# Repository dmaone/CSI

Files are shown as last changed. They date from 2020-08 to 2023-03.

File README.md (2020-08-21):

# CommonSense Info

This repo holds CommonSense project paraphernalia: pinouts, assembly guides, gerbers, PCB photos - you name it.

[Common](Common.md) - common stuff, like layouts and threshold configuration

[Capacitive](Capacitive.md) - for Model F, beamspring, Topre, probably Plum

[Inductive](Inductive.md) - for ITW ferrite core switches (MagValve, Cortron, Licon..). Probably other inductive ones.

[uSwitch](uSwitch.md) - Honeywell MicroSwitch. SDxxxx

[Common](Common.md) - common stuff, like layouts and threshold configuration

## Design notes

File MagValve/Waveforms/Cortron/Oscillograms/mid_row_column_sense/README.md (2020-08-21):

In this experiment, probes are connected across the column, and the key in row 6 is pressed.

Somewhat expected, this doesn't cause any change to the columns closer to ground.

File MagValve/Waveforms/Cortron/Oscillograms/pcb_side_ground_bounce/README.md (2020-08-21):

This is measuring ground bounce between controller gnd and rows(?) gnd, when different rows are driven.

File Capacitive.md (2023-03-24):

# Capacitive stuff, IBM or otherwise

## Only switch-specific things are here. Most of the doc is in [Common.md](Common.md)!

# Planning: pinouts

* It is STRONGLY RECOMMENDED to set matrix size to your physical matrix size.
* There are some ready-made configurations for the default pinout in `config.h`.
* YOU MUST USE CONTIGUOUS ROWS/COLUMNS, STARTING FROM ZERO.
* Pins on the board are marked `0.0`, on envelope - `P0_0`, and in PSoC Creator - `P0[0]`. All 3 refer to the same pin. `2.3`-`2.7` means "2.3 to 2.7, including".
* Effort is made to make pins contiguous, but that's not always possible, so pay attention.

### Default pinout: Project "Capsense"

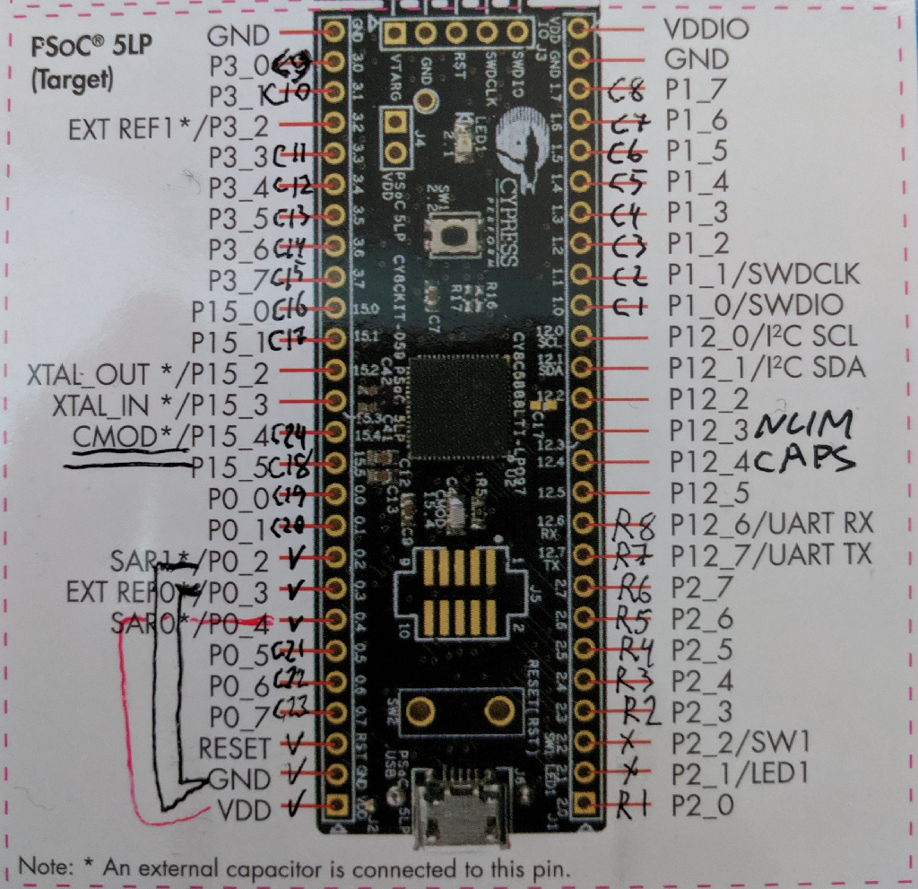
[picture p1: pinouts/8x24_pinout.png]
default pinout

**WARNING** to use column 24, **R5** (between `0.1` and `12.6`) MUST be removed.

If you don't - column will always read zeroes. Which is, for a NORMALLY_HIGH switch like Beamspring, means they will appear **PRESSED ALL THE TIME**.

* D0: `0.2`. Must be connected to the nearest `GND`.
* Guard: `0.3`. Must be connected to the nearest `GND`. Separate wire is **HIGHLY RECOMMENDED**
* ADC Vref: `0.4`. Must be connected to the nearest `VDD`.
* Rows: `2.0`, `2.3`-`2.7`, `12.7`, `12.6`
* Cols: `1.0`-`1.7`, `3.0`, `3.1`, `3.3`-`3.7`, `15.0`, `15.1`, `15.5`, `0.0`, `0.1`, `0.5`-`0.7`, `15.4`.

### If you're changing the pinout
* You'll need 35 pins. That's not much more than the kit has - so choose the layout wisely.
* rows are top(`Rows0[0]`) to bottom(`Rows0[7]`), columns are left(`Cols[0]`) to right(`Cols[23]`).
* Keep in mind that in FlightController everything is 1-based so normies can use it, so rows will be 1 to 8.
* P12(all pins of it) cannot be used for analog connections. That means you can only assign Rows to those pins.
* It is better to separate Rows and Cols by a pin electrically connected to the ground, but not necessary. If you use adjacent pins - one matrix cell will have higher readings, that's all.

## Additional Hardware configuration hints
* If key monitor only shows zeroes, no matter which keys you press - set ADC resolution higher.
* If even at 12 bits it still doesn't work - increase charge delay. Recommended setting is 18.
* If several keys fire at once - set longer discharge delay. I found that 180 (10 microseconds) works pretty well, but you can go even higher for increased EMI rejection.

## Configuring thresholds
**NOTE** for beamspring, invert direction, so max->min and adjustments are negative.

**!!!NOTE!!!** If you see double presses on some keys, set threshold higher - just under the steady pressed state. Some keys have physical bounce and there are two peaks. Controller is too fast and sees this as 2 keypresses.

Short version ():
* Click "Key Monitor" button.
* Click "Start!". Get the idea of levels that should be there - press keys, observe readings going up and down. Small numbers below 7-segment indicators are min/avg/max.
* Click "Stop!". Select "Max" into dropdown near the "reset" button, click "Reset", "Start!".
* Wait 15 seconds or longer, while readings stabilize.
* click "Stop!". Click "Set thresholds". Close window.
* Click "Thresholds" in the main window. put a small positive value (see below) into adjuster spinbox, click "Adjust".
* Click "Apply".
* Close threshold editor. Select "Config -> Upload" in menu. Test. Once you're satisfied with results, "Command -> Commit".

Thresholds should be set ~2x higher than most of the matrix settles on. For beamspring - probably 75% of the highest reading.
**TEST SETTINGS BEFORE COMMITTING**. If you get thresholds wrong - there will be a red "UNSAFE" light in the status bar and keyboard will refuse to produce output. It's supposed to retest settings after you upload. If it doesn't - click "Scan", it will try to restart scanning.

### Debugging the matrix
If something is wrong - you can still use matrix monitor using the following trick:
* open matrix monitor,
* make sure the mode is "Now"
* click "Start!"
* go to main window
* click "Scan"

The numbers under the "LCD" numbers are min/avg/max since last reset. Looking at those will tell you A LOT about what controller sees - but not everything, because in normal mode controller processes about 30 thousand rows per second and there is no way to transmit that amount of data over USB 2.0.

**WARNING** exit this mode in the reverse order (or by pulling out the USB plug), otherwise you'll likely have to reboot.

This is mostly useful for beamsprings - because all keys are down in beamspring by default. Model F is much easier - everything is up and you can just press a key to observe the effect. So, recommended debugging strategy - pull out the PCB, lay it down over grounded conductive surface, start matrix monitor, put one flipper (or a small coin) over the PCB and observe the changes. If several rows/columns change at the same time - you have a short between those, find it. If readings are normal but assembled keyboard is unstable - it's likely a ground problem.

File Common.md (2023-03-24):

# Things that are applicable to firmware in general, not switch-specific

### ExpHdr (AKA "Solenoid connector")
Configured to blink the kit's LED on keypress. `12.4` is a CapsLock LED, `12.3` - NumLock.

**Leave it alone, unless you really know what you're doing. You can permanently damage GPIOs if you fuck up here.**

DO NOT POWER ANYTHING FROM GPIOs. Max GPIO source current is 4mA. FOUR. MILLIAMPERES.

So, `ExpHdr0`(`12.3` by default) would be "enable" line, and `ExpHdr2` (`2.1`) is the "fire" line. Delay settings are in "Hardware" section of FlightController. `ExpTgl` "USB scancode" toggles between normal operations and "all GPIOs are pulled to the ground".

# Soldering

I recommend flashing initial firmware plus some safe configuration first. It's just easier to plug the empty kit in - for initial flashing you'll have to plug the whole kit into standard USB socket, and that might be hard with a big hunk of metal attached to it.

### SOLDER THE KIT SO YOU CAN SEE THE CHIP.

It's in CAPS because I was stupid enough to solder it chip (and LED) facing backplate and blinking LED debugging without seeing the led is pain.

### Grounding considerations
Ground. Does. Not. Matter.

As long as you connected ALL the metal parts adjacent to PCB **and** PCB ground with ANY of the GND pins of the kit - you are fine. Stop worrying about it.

If your PCB doesn't have any vias - MAKE SURE YOU CONNECTED ALL GROUND TRACES ON BOTH SIDES OF THE PCB to controller ground. Floating traces are bad, mmkay.

Except if you see very unstable readings (matrix monitor over 15 seconds with no keypresses shows something like 1/50/255). Then you _probably_ have a ground quality issue.

When in doubt - use star ground. That is, connect all the things that must be grounded (basically, ALL THE THINGS except rows and columns) to a single point, using different wires.

## Hardware configuration hints
* If you're using Linux and can't connect - run as root OR fix your device permissions. No, I don't find fucking with your udev enjoyable, thank you very much.
* If you see the red UNSAFE in the bottom right corner and what to know why - see "Debugging the matrix" in switch-specific README
* If you see double actuations on keypress - increase debouncing steps.
* If you haven't touched ExpHdr pins - "Solenoid" mode and drive time set to 100 will make a LED on the kit blink with every keypress (not in setup mode). Smaller setting will decrease brightness.

# Flashing "default" firmware
This section is removed to stop causing stupid questions.
You MUST build. Deal with it.

# Building custom firmware
You'll need Windows machine. Mac with VirtualBox will do - but a couple of notes there.
You'll need to download [Virtualbox](https://www.virtualbox.org/wiki/Downloads) (v5.2.2 was used) - don't forget the extension pack - and a [windows image](https://developer.microsoft.com/en-us/microsoft-edge/tools/vms/) - I used "MSEdge on Win10". Download, unpack, click the .ovf, wait for import to complete. Then open settings (right-click, "Settings"), click "Ports", select "USB" tab, enable USB 2.0 controller, click the plug with blue dot. THIS WILL CONNECT ALL NEW USB DEVICES TO YOUR VM. Run the VM now. You have your windows development environment now. Download PSoC creator into VM, install (typical works just fine), and continue.
Linux with Virtualbox will probably work too - but not tested as I don't have any hardware running Linux and running virtualbox inside virtualbox is not something I plan to do anytime soon.

Download and install [PSoC Creator](http://www.cypress.com/products/psoc-creator-integrated-design-environment-ide) - you actually can download without suffering akamai download manager. Typical install works just fine. v4.3 was used, though newer should work too.

### Bootloader
You likely don't need to change bootloader - but building it will verify that your development environment is set up correctly.
* Open PSoC Creator
* File -> Open -> Project/Workspace, find "CommonSense.cywrk" and open it.
* Select "Project 'Bootloader'" in "Workspace Explorer" on the left, right-click, "Set as Active Project".
* **IMPORTANT:** Select "Release" in the combo box on the top toolbar that likely displays "Debug".
* Right-click again, "Device Selector", find and select "CY8C5888LTI-LP097". It's likely selected already.
* Press Shift-F6 to build bootloader.

#### Important troubleshooting notes
* "DTD prohibited for security reasons" means "you used ClownZip, and it couldn't decompress the .zip"
* "Unable to find component X" - right-click on top-left item in the left tree editor ("Workpace 'CommonSense' (7 Projects)"), click "Update Components". It should download the missing parts.
* Compilation errors: pay attention to the **IMPORTANT** warning. If it says "Release" - ask at DT, but see the top paragraph. You get support that you paid for (and you can't pay and there are no plans for that).

### Firmware
I will use "Capsense" as a project name, but if you don't want to have merge conflicts in config.h every time you pull - you can copy+rename the project. You will only copy programmable hardware settings (which will not change - I run that since 2017 and never had to) and config.h. Everything else will NOT be copied, so you will get all the updates.

Do a smoke test first: Repeat the "Bootloader" part for the Capsense project.

When that succeeds - it's a good time to make your firmware customizations.

`Capsense.cydsn/config.h` is a config file. You can set number of rows, columns and layers there, as well as switch type. There are presets for popular configurations, activated via `#define HARDWARE_VARIANT HW_X` - or you can use `#define HARDWARE_VARIANT HW_CUSTOM` if you know what you're doing.
Again: **build without any changes first**!

For non-default pin mapping: Expand a project in the left pane, click "Pins" in "Design Wide Resources". You will see chip model and a table in the big window. Assign pins according to plan.

The Big Moment: plug the kit in. The "gold fingers" part goes into the USB socket.

Press "Ctrl-F5" (Debug -> Program). PSoC Programmer will likely demand to update KitProg - it will walk you thru. Refer to "Flashing "default" firmware" section for troubleshooting tips.

---
It's time now to disconnect the board, peel that polyimide film off the micro USB socket, find the micro-USB cable in the cable mess under your table, and plug it into "Target" part of the kit.

..I was able to plug _both_ ends into the same USB hub (thinkpad docking station) without frying anything - but your mileage may definitely vary.

You may optionally break the kitprog away in a symbolic gesture, but a) if I were you, I wouldn't - not until you set everything up successfully at least - and b) cut the laminate at the snap-off line first. Doesn't have to be all the way (though you certainly can if you're looking for excuse to dremel things), but enough so the board doesn't buckle so horribly and I2C/RS323 traces are not lifted from the substrate. Oh, and soldering probably have to wait until this moment at least.

# FlightController

FlightController is an utility which allows runtime configuration of keyboard parameters

The building process is quite involved (See Qt-build/README.md in CommonSense) - at least on Windows. OS X requires homebrew AND XCode, but is scriptable.

There are Windows and OS X version in the [Releases](releases) section of CommonSense repo.

## Configuring layouts
Pretty straightforward. If thresholds are configured, pressed keys will be highlighted by "yellow highlighter" color and focused on. If you have another keyboard - pressing a letter there will change combo box value to that letter, allowing for VERY quick layout generation.

"Layer mods" configures what Fn/LLck buttons do. Press F to ~~pay respects~~ scroll to those - several times. It will cycle thro all USB scancodes starting with "F".

"Import" and "Export" will load and save to file. Format is compatible with xwhatsit layout files.

IF you see keypresses in setup mode, but not in normal - check out global.h, #define NOT_A_KEYBOARD. If it's 1 - change back to zero.

## Macros and delays
Figure it out yourself, please. It's not that hard. Delays are the _library_ of delays which will be used in macros.

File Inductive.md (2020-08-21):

SO YOU HAVE COME. (https://www.youtube.com/watch?v=k0VvMUD5vBY)

Remember that guy? Yeah. This is _that_ level of difficulty.

There's no matrix monitor - the programmable hardware is totally different and is, essentially, a 4-channel xwhatsit reimplementation, the only deviation being a separate DAC (hence threshold) per channel, each channel sitting behind a 4-channel multiplexor.

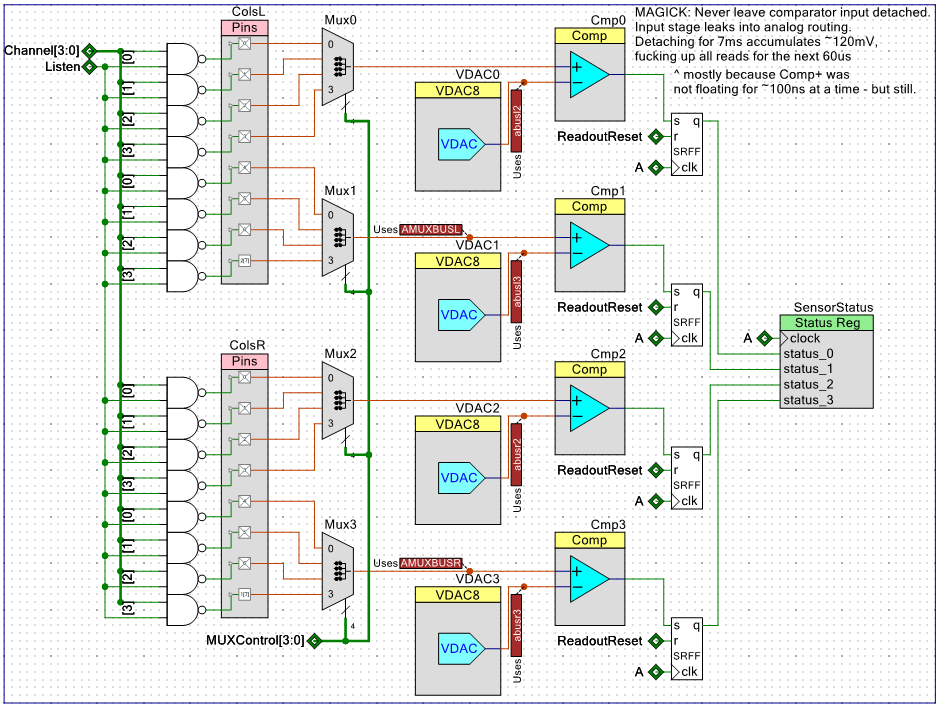
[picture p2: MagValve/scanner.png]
scanner


So it's back to blind tuning, and there's no autotune support xwhatsit util had. Partly because I'm a bit short on time recently, but largely because out of 3 test devices all 3 worked with same thesholds. I was able to literally solder a different keyboard to the same controller and it just worked with the thresholds from another - and to program a new controller, solder it to the third keyboard and just needing to correct for just a couple of keys, problem being "spacebar triggers if you press basically anything else".

Not much is known about what's _really_ going on inside the matrix, but I intend to get a bigger scope and figure this out in a couple of weeks while I still have access to the hardware.

# Before you begin
* If you're wondering what you've got - [there is a guide](http://telcontar.net/KBK/ITW/)
* This is optional, but highly valuable for troubleshooting: take high-res digital photos of both sides of your keyboard. High-res enough for traces to be 5px wide. Invaluable for tracing things.
  * Bonus points if you can fit all the board on one photo - stitching multiple photos is an ungrateful job.
  * Reference photos (too large to be inlined):
	  * Black is ground, colors are rows/columns. They are messy, because it's not easy to find 20 different colors and I had to resort to patterns.
	  * [Cortron 35-500079](MagValve/Cortron_35-500079_map.jpg) from [this mysterious beast](https://deskthority.net/viewtopic.php?f=62&t=19441)
	  *  [Cortron 55-500056](MagValve/Cortron_80-551101_rev_D.JPG) from [Raytheon model 930898-94](https://deskthority.net/viewtopic.php?f=2&t=23644)
	  * [Harris F190 22D](MagValve/Cortron_125-500451_map.jpg)
	  * [Nifco EKBB005A](MagValve/Nifco_EKBB005A.jpg) from [Telecomet type Σ3100](https://deskthority.net/viewtopic.php?f=2&t=23262).
* Find row/column driver chips. They are relatively inconspicious: rows terminate at 74145(can be 2 of those) and columns - at 7442. Those are both BCD decoders, 7442 is stronger drive.
  * If your board has Mitsubishi chips - the conversion formula is M(53200+{74-series model})P:
    * 7416(74**0**16) is M53216P.
    * 7442 (74**0**42) is M53242P
    * 74145 is M53345P
  * Sometimes, both decoders are 74145.

# Prepping the board
## LED concerns
Some boards have LEDs with drivers that are active high. So far, 2 ways to drive those was discovered:
* [SN]7416, LEDs hanging from power rail
* 75452 with ganged outputs, driving LED directly.

If you want to use those - don't **ACCIDENTALLY** power the whole board.
Recommended way is to cut drivers' Vcc trace from the rest of the board and power them from controllers' VDD or VDDIO pins. This can be awfully inconvenient in case of LEDs hanging from power rail, in which case you might elect to power the whole board, but watch for USB power consumption - don't fry the USB port.
**WARNING: Don't power LEDs** (or anything else!) from GPIO pins. Not only it won't work, **you'll fry the GPIO**.

## Remove the drivers
Hot air is your weapon of choice, but solder wick or even dremel (From the top side!) work just as well - you won't need those anymore. Just try not to damage the pads.
## Find columns common point and ground it
If you see 10-ish diodes on the PCB, connected together on one side - congratulations, you found it. Diodes may be scattered around the PCB (as is in Harris case) - but then they all connect to a common bus.
**Cross-check:** those diodes are connected to 7442 via keyboard matrix.
Connect the diode cathodes (the band side), to the ground rail. Double check it's ground rail - just shorting diodes is not enough as their common point is NOT ground.

NOTE: You might find MC833P chip instead of diodes. It is, essentially, 8 diodes.

If you plan to use LEDs (see below), you may want to desolder diodes and connect the column traces to the ground directly.
## Find rows common point and ground it
Look for a swarm of jumper wires (or vias) between row traces, near 74145(s). Connect any of those vias to ground (
* Connect common point of rows (it's close to 74145(s), look for a swarm of jumper wires (or vias!) between tracks that go alongside the row traces) to the ground rail.
**PRO TIP:** pin 7 of 74145 is ground.

## Solder the interface wires
Find the place for the controller, trace, measure, cut, tin, solder.
Wire quality seems not to matter - I used ribbon cable with some janky totally-not-copper conductors, and it worked OK 4 times out of 4.

I used different ground conductors for rows and columns - there's significant current flowing in rows, after all - but this is totally optional.

**!!WARNING!!** Cortron makes PCBs from unbelievably shitty phenolic paper and pads delaminate if you just look at them wrong, let alone touching. Be extra careful. They also give off awful ammonia smell when heated.

# Preflight checks
Resistance between the ground and any column or row wire end must be 1.5 to 2.5Ω. It seems to be around 0.2Ω/switch, but my ohmmeter has 0.1Ω scale, so it's not very trustworthy.

If all rows have same resistance to the ground and it's around 360/580Ω - you have not grounded the rows common point (see above).

# Assembly
Most recommendations from capsense part still apply, except for pinout.

## DO NOT touch columns. Not even reorder.

Columns laid out that way because it's the only way to fit 4 analog MUXes onto the chip.

Don't worry about column order. Solder in a way that will make cabling easier. You'll fix it all in layout. Cortron with a numpad has batshit insane layout anyway, you won't make it worse.

## Severe Weirdness Ahead
"Rows" work MUCH better when routed to where 7442 was.
I know, I know, 7442 drives physical columns. But since physical layout is insane anyway, there's no harm transposing it. It literally *cannot* be made worse. In return you can make matrix "shorter" for faster scanrate - and considering level of debouncing MagValves require it's a pretty useful change.

## Default pinout

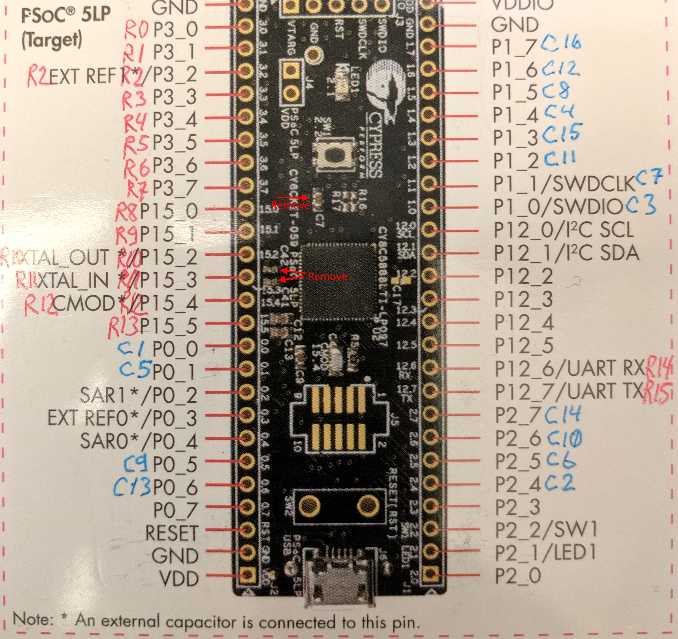
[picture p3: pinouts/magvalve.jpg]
Default pinout


Note that you will need to desolder 3 capacitors if you don't remap the rows. It's not that hard - just use the wide tip and some flux. Rest the tip on the capacitor and just nudge it off the pad after a couple of seconds. Sometimes just lifting the tip will pull the capacitor away.

# First Startup

First run will almost certainly result in [UNSAFE] condition.
* Go to hardware settings, verify charge delay is 20+ and discharge delay is 3-4.
* Debouncing must be set to **at least** 4 - 16 is recommended for the fist run.
* Set all thresholds to 15, apply values.
* Upload, COMMIT (Warning: takes several seconds), REVERT(essentially just a hard reset to ensure settings are applied), reconnect.

This usually results in a working keyboard. If some keys don't register - drop thresholds to 10, don't forget to upload changes. The best way to verify operation is to open Thresholds window while keyboard is in setup mode. Pressed key position will be highlighted yellow.

* There can be a key that trips when others are pressed. Bump that key's (or all keys) threshold couple notches
* Some keys might flicker. That's usually a sign of a threshold too high.

Once you achieved stable operation - find lowest debouncing interval that's still stable. I found 4 to be OK, less than 4 starts to give off spurious keypresses.

# OK, so it doesn't work.

## I pressed 20 keys at once and there's key spam
[STOP IT!](https://www.youtube.com/watch?v=4BjKS1-vjPs). I'll eventually have a separate doc with oscillograms which explains why that happens. But seriously. Stop it.

## Single row/column doesn't register
* For rows: make sure you removed capacitors indicated on pinout picture.
* Desolder affected line from controller. Verify resistance between line end and controller's ground pin.

## Scanner trips the sanity check no matter the settings

### Diagnostics
Follow this checklist, uploading config after each change. Stop when it's green AND some keys register.
* Set debouncing to 16.
* Set discharge delay to 50 or even 100.
* Set thresholds to 250. It should be green but keys wouldn't work (CHECK if they are!).
* Lower threshold to 100 - 50 - 25 - 15

### Interpretation
* Debouncing or discharge delay fixed it
  * Wires too long and/or too thin?
  * EMI sources in close vicinity? (dimmable LED lamps, DC electric motors, aliens...)
  * If the board is powered - interference from the old controller?
* Thresholds either high (>30) or very unstable
  * Verify **physical** row and column common points are securely grounded.
    * For rows: Verify low (<0.1Ω) resistance between ground and every between-rows trace.
    * For columns: Try to desolder (or just cut out) the diodes, and connect the cathodes (the pads that go to columns, not the common rail) to the ground. Verify resistance between column line and the ground.

# Some insane shit is happening
* Some keys don't register, or only register when you touch the plate with your other hand.
* or register only if pressed FIRMLY, and even then may only intermittently register.
* or register only if pressed firmly AND then shifted left/right/up/down.
* or register only you put something **FOR THE LOVE OF GOD, NON-CONDUCTIVE** under one side of the PCB and press firmly.

Congratulations, you're in for the Total Resoldering.

## If you have a scope
This won't save you from the resoldering. But you can at least confirm that rework will help.
Connect your scope to the row which has a problematic key, and set discharge delay to 10-15 (don't forget to move it back to ~4 after the experiment! Prolonged shorting of the GPIO to the ground is a surefire way to fry it!) and observe.

Let's look first at the good signal first:

![good][MagValve/good.png]

And now at bad:
![bad][MagValve/bad.png]

It's mostly explained in the pictures - but one tell-tale sign is left out: the post-impulse oscillations. The good signal drops to the ground quickly and stays there. The bad is much wigglier. If you see that - rework is your ticket. If not - I don't know what it is, you're on your own. I can speculate looking at your scope screenshots, but by the time you're reading it I won't have ANY cortron boards in my reach. 

## Total Resoldering
Leads on at least some of those switches are made of some strange material which repels 37Pb63Sn solder.

How to tell: touch the solder joint with a soldering iron (give it some flux up front, because that thing was made 50 years ago, it has oxide CRUST on it, not "film") - and observe solder JUMPING away from the lead.

It takes copious amounts of RMA flux (I used DeoxIT RSF-R80-2) and a scraper tool to convince it to take some tin. The tool (and what happens after heating the joint) looks like this: https://www.instagram.com/p/B251_1UjHZ7/. It is made from a diode because that's what I had on hand. It doesn't have to be a diode - just some sturdy wire with a loop on it. Or a wire brush. Improvise.

Leads had to be bathed in flux and scraped for 10-15 seconds, repeatedly - with new dose of flux applied to the lead every round.

I am NOT joking about scraping.

Even with scraping, after washing away the flux residue I see lots of "cold joints" and even holes in the solder between lead and the pad - but it works, and it's not my keyboard so I'm not going to switch to OA flux (or even IA/tip tinner) and have a chance to corrode everything in a couple of years. RMA barely cuts it, even after 30 seconds of bathing in a continuous supply of it.

Unfortunately, I didn't measure resistance before the resoldering operation, so I don't know how large it was. If you encounter one of those boards - please don't forget to measure the resistances beforehand and drop me a note - by email or via PM on DT - or even in the topic.

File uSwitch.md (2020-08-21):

# Untested prototype firmware

Supposedly works with "microswitch" keyboards.

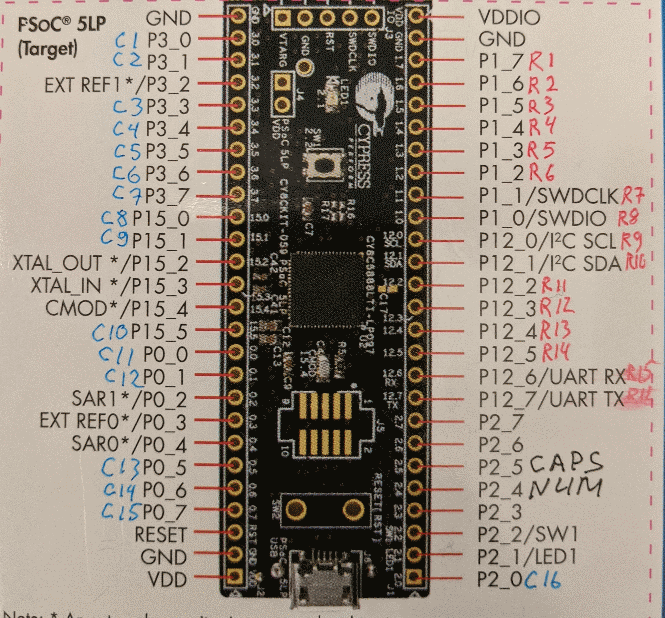
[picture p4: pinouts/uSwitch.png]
default pinout


Scans at 200kHz, so should have plenty of time detecting those 60us pulses from pulse switches.

Please reuse pullup resistors from original keyboard - but if you can't and scan doesn't work with bare switches - go to TopDesign.cysch and change pins to resistive pullup and initial drive state to "High (1)". That should do the trick.

If you can get it working - let me know :D

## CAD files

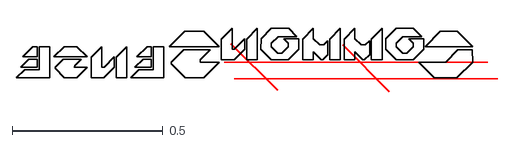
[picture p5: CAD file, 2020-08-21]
PCB/commonsense-logo.dxf
1.60 x 0.209

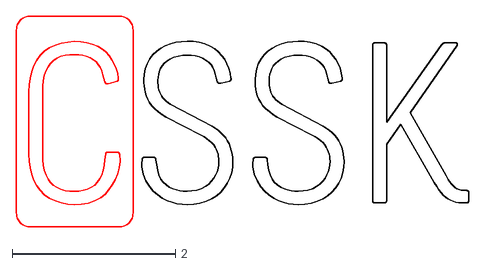
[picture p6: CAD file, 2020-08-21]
PCB/CSSK/CSSK2.dxf
5.54 x 2.58

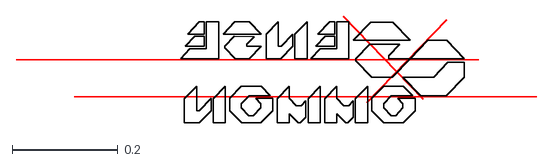
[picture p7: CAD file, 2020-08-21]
PCB/commonsense-logo-compact.dxf
0.983 x 0.202

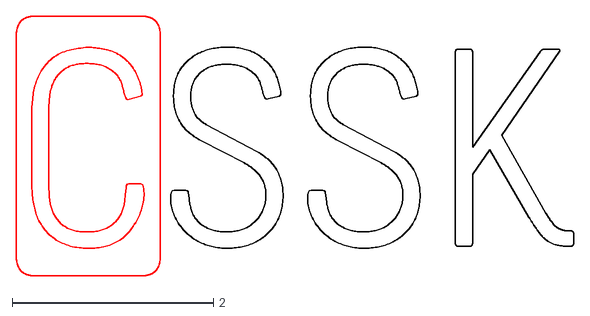
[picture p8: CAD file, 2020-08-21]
PCB/CSSK/CSSK3.dxf
5.54 x 2.58

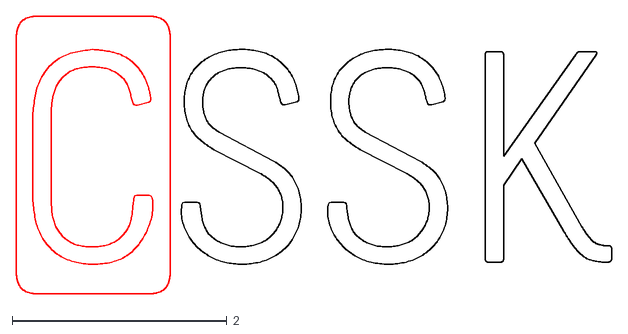
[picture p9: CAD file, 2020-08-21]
PCB/CSSK/CSSK9.dxf
5.54 x 2.58

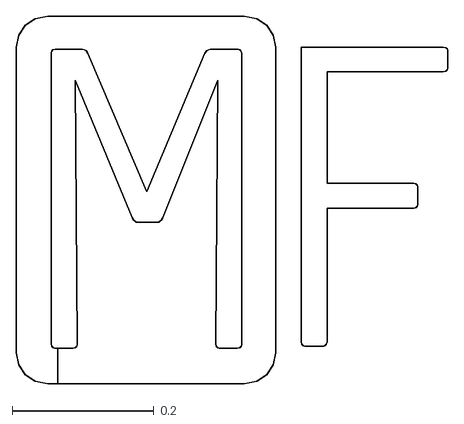
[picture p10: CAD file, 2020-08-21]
PCB/MF-logo.dxf
0.608 x 0.519

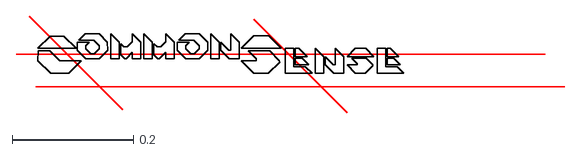
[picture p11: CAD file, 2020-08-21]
PCB/commonsense-logo-24mm.dxf
0.905 x 0.159

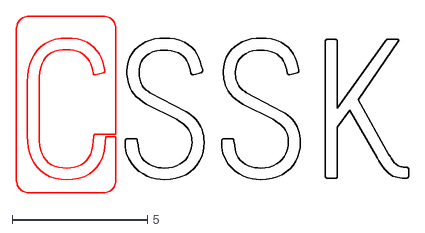
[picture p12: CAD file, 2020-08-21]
PCB/CSSK/CSSK.dxf
14.5 x 6.53

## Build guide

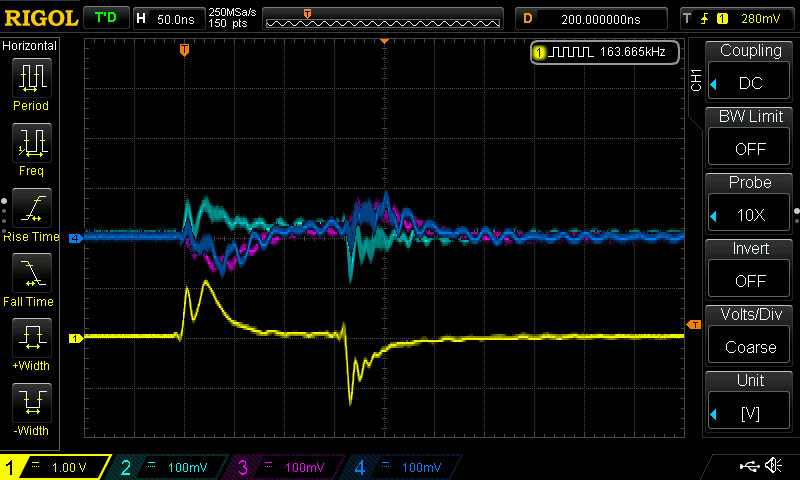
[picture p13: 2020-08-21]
MagValve/Waveforms/Cortron/2_rows_ground_at_far_end/DS1Z_QuickPrint12.png

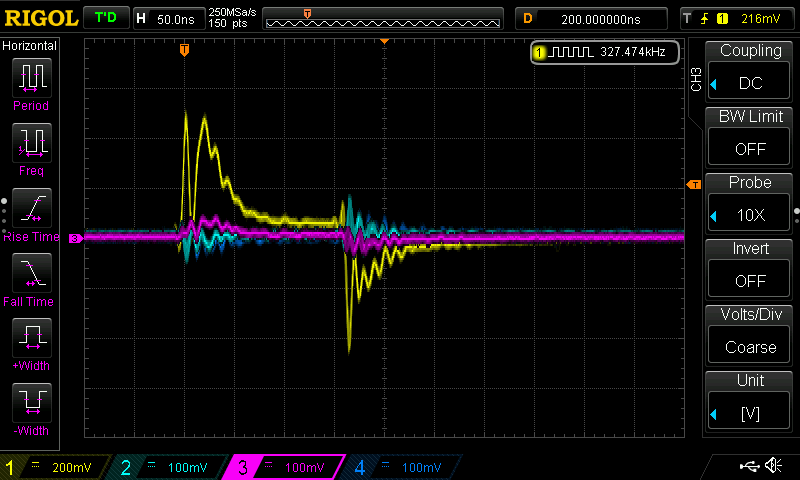
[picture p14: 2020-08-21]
MagValve/Waveforms/Cortron/2n_matrix/DS1Z_QuickPrint7.png

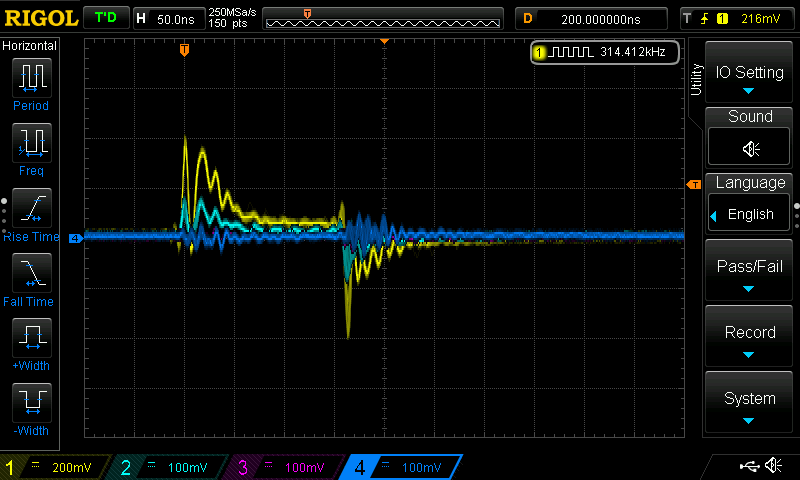
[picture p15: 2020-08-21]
MagValve/Waveforms/Cortron/2n_matrix/DS1Z_QuickPrint1.png

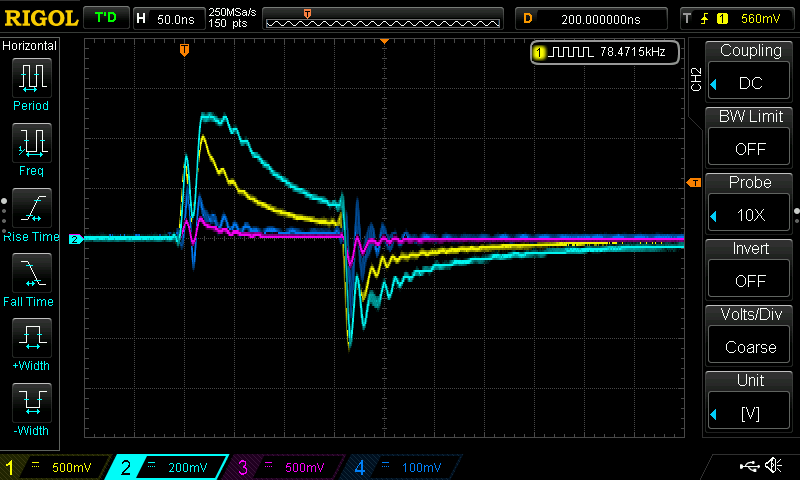
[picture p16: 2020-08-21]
MagValve/Waveforms/Cortron/5x4_rows/DS1Z_QuickPrint7.png

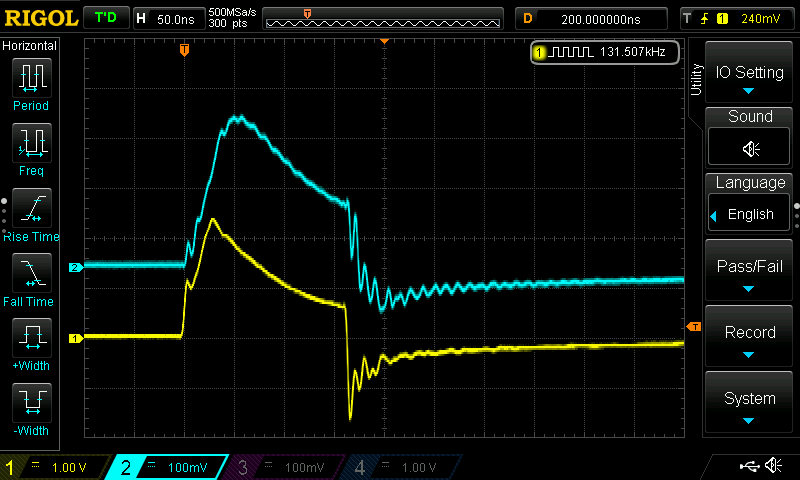
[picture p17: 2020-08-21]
MagValve/Waveforms/Cortron/tall_single_chain/DS1Z_QuickPrint7.png

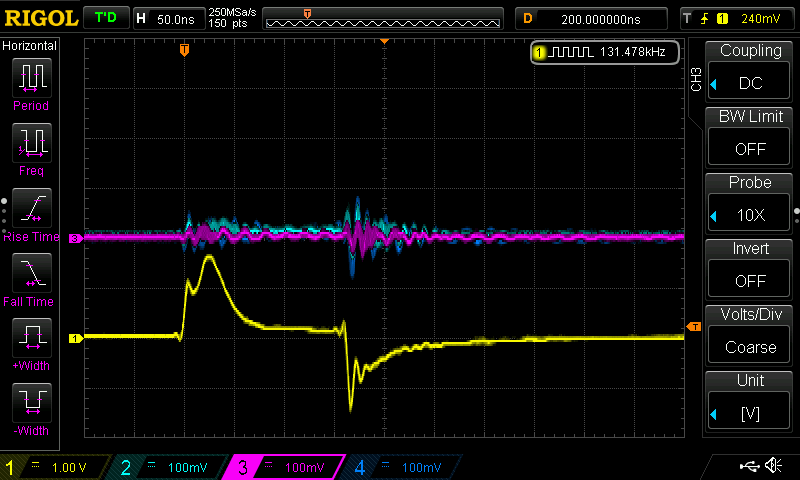
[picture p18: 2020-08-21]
MagValve/Waveforms/Cortron/tall_grounded_chain/DS1Z_QuickPrint10.png

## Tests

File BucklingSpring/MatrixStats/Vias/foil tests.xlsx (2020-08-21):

All sizes are in 1/32th of an inch.
Drive wdth | 8 |  | Noise normal | 2
Sense wdth | 9 |  | Noise no gnd | 6
Gap | 2
 |  |  |  | Vias |  | No vias |  | contact patch, sq. 32s
Size | Width | Height |  | Normal | No gnd | Normal | No gnd | drive | sense | Min | Sum
20x12 | 20 | 12 |  | 48 | 75 | 15 | 25 | 96 | 108 | 96 | 204
20x8 | 20 | 8 |  | 30 | 50 | 11 | 19 | 64 | 72 | 64 | 136
12x10 | 12 | 10 | Drive side | 20 | 30 | 10 | 15 | 80 | 20 | 20 | 100
 | 12 | 10 | Sense side | 13 | 15 | 7 | 13 | 10 | 90 | 10 | 100
 | 12 | 10 | Max | 24 | 40 | 12 | 18 | 50 | 50 | 50 | 100
 |  |  |  | Adjusted for noise: |  |  |  | Per sq. 1/32” min
 |  |  |  | Vias |  | No vias |  | Vias |  | No vias
 |  |  |  | Normal | No gnd | Normal | No gnd | Normal | No gnd | Normal | No gnd
 |  |  |  | 46 | 69 | 13 | 19 | 0.4791666667 | 0.71875 | 0.1354166667 | 0.1979166667
 |  |  |  | 28 | 44 | 9 | 13 | 0.4375 | 0.6875 | 0.140625 | 0.203125
 |  |  |  | 18 | 24 | 8 | 9 | 0.9 | 1.2 | 0.4 | 0.45
 |  |  |  | 11 | 9 | 5 | 7 | 1.1 | 0.9 | 0.5 | 0.7
 |  |  |  | 22 | 34 | 10 | 12 | 0.44 | 0.68 | 0.2 | 0.24
 |  |  |  |  |  |  |  | Per total useful area
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
